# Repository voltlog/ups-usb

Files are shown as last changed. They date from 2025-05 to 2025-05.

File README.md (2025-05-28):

# ups-usb
This repo contains the isolated USB to serial board that I designed for a Serioux LD600LI UPS to get it to talk reliably with NUT.
Project was designed using Kicad V8.  For more information check out [Voltlog #503](https://youtu.be/ZeoCBQmW2Rw)
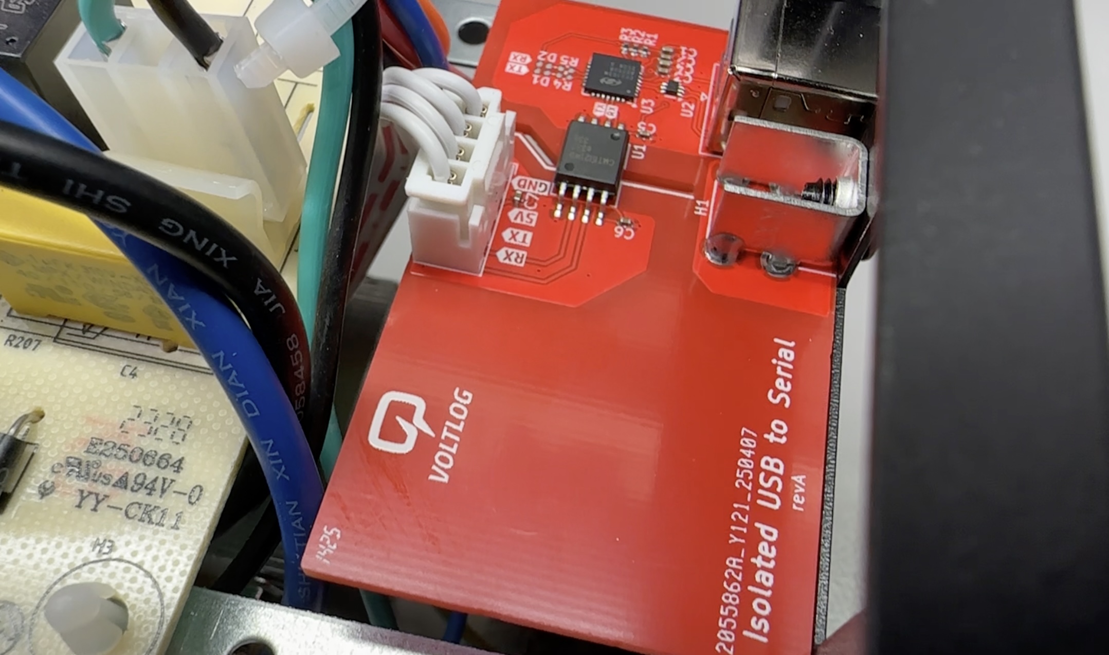
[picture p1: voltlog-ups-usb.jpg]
Image of the assembled PCB


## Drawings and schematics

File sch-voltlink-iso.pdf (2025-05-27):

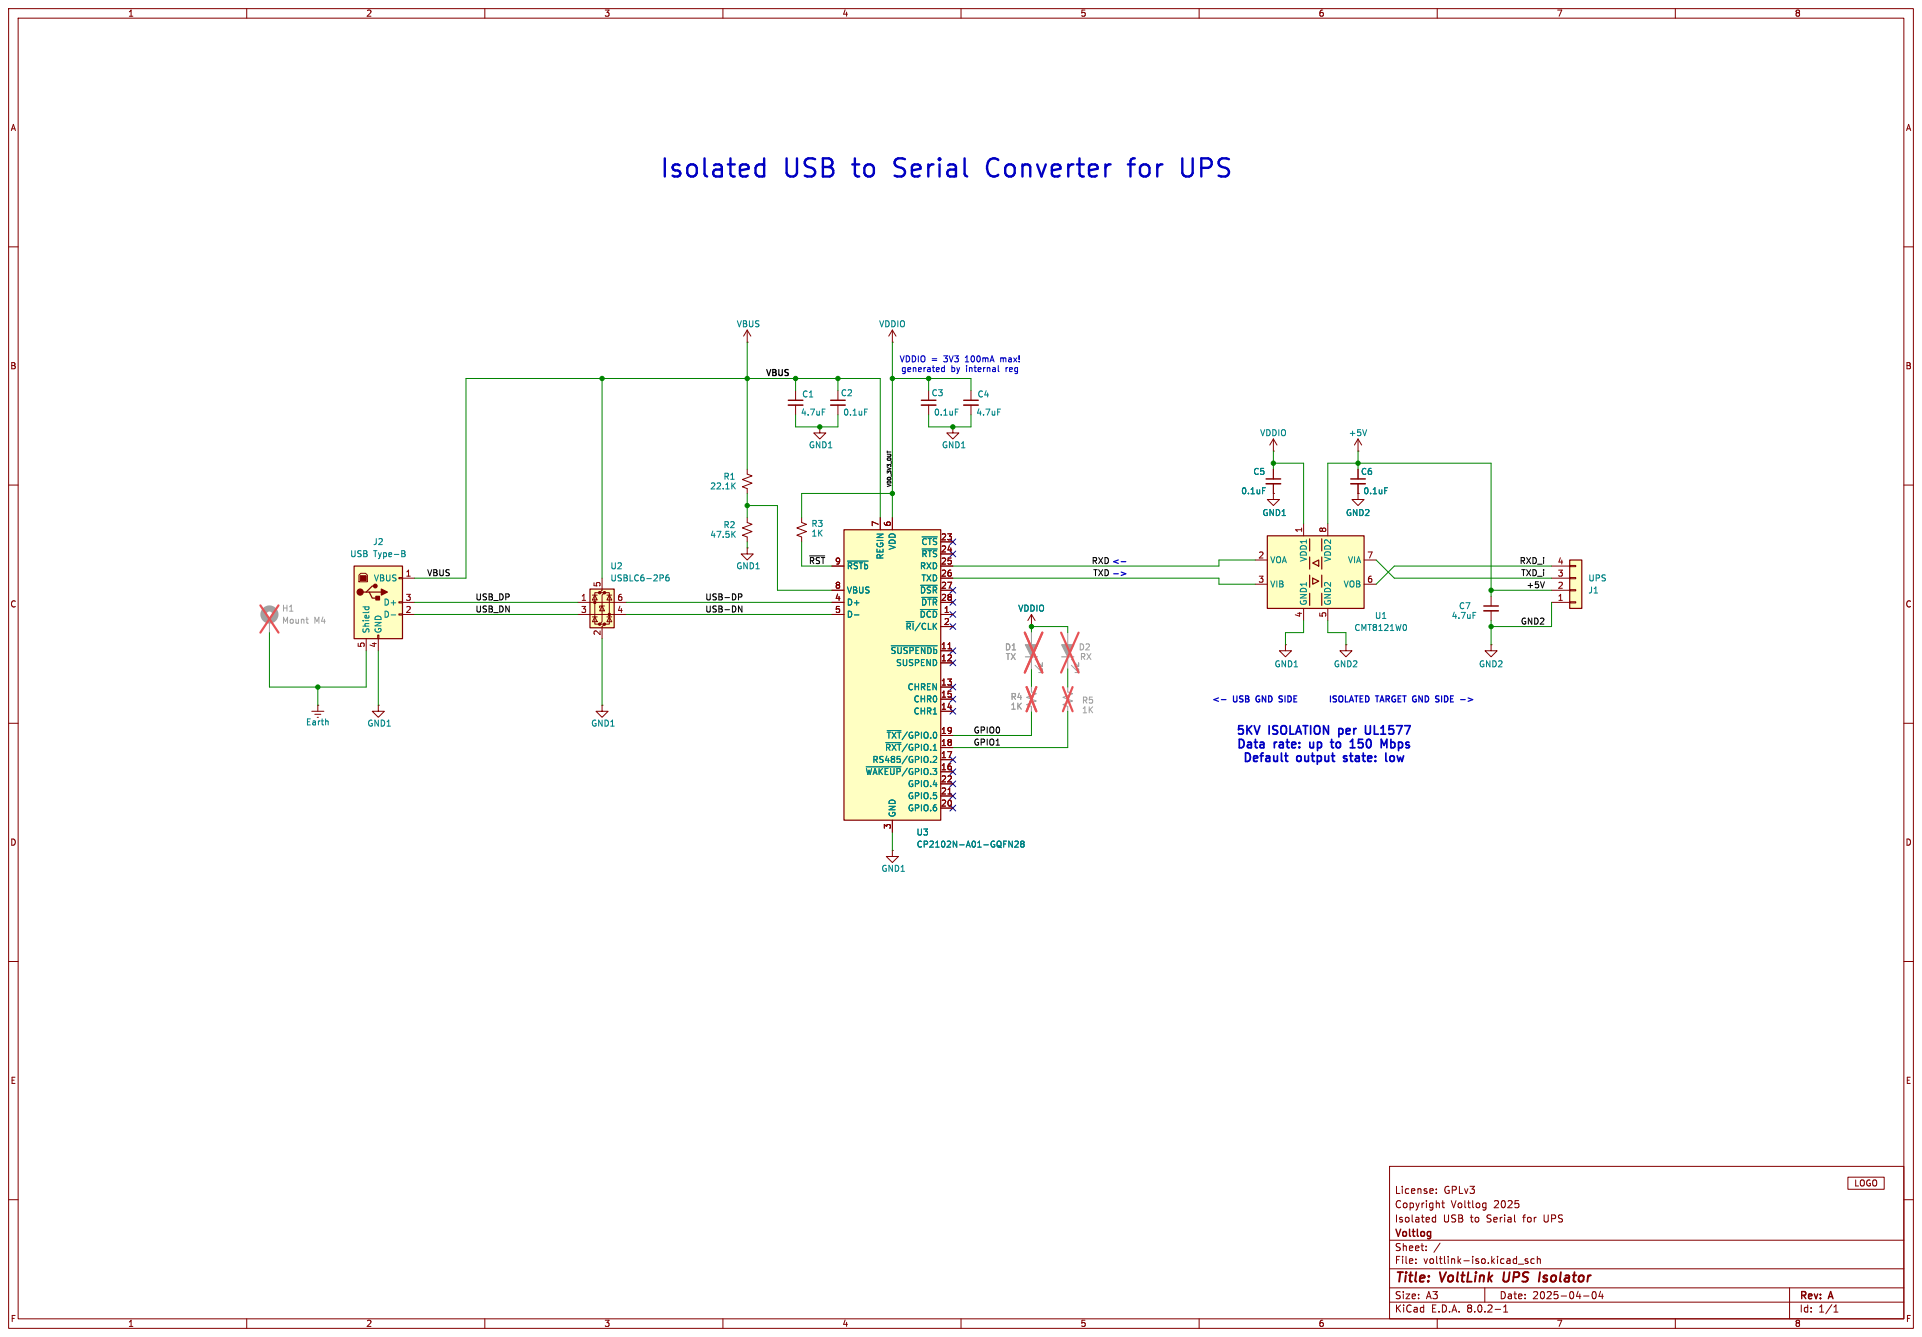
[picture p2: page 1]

<- Isolated USB to Serial Converter for UPS

ISOLATED TARGET GND SIDE -> VDDIO

Data rate: up to 150 Mbps
Default output state: low

Id: 1/1 Title: VoltLink UPS Isolator File: voltlink-iso.kicad_sch Sheet: / Voltlog

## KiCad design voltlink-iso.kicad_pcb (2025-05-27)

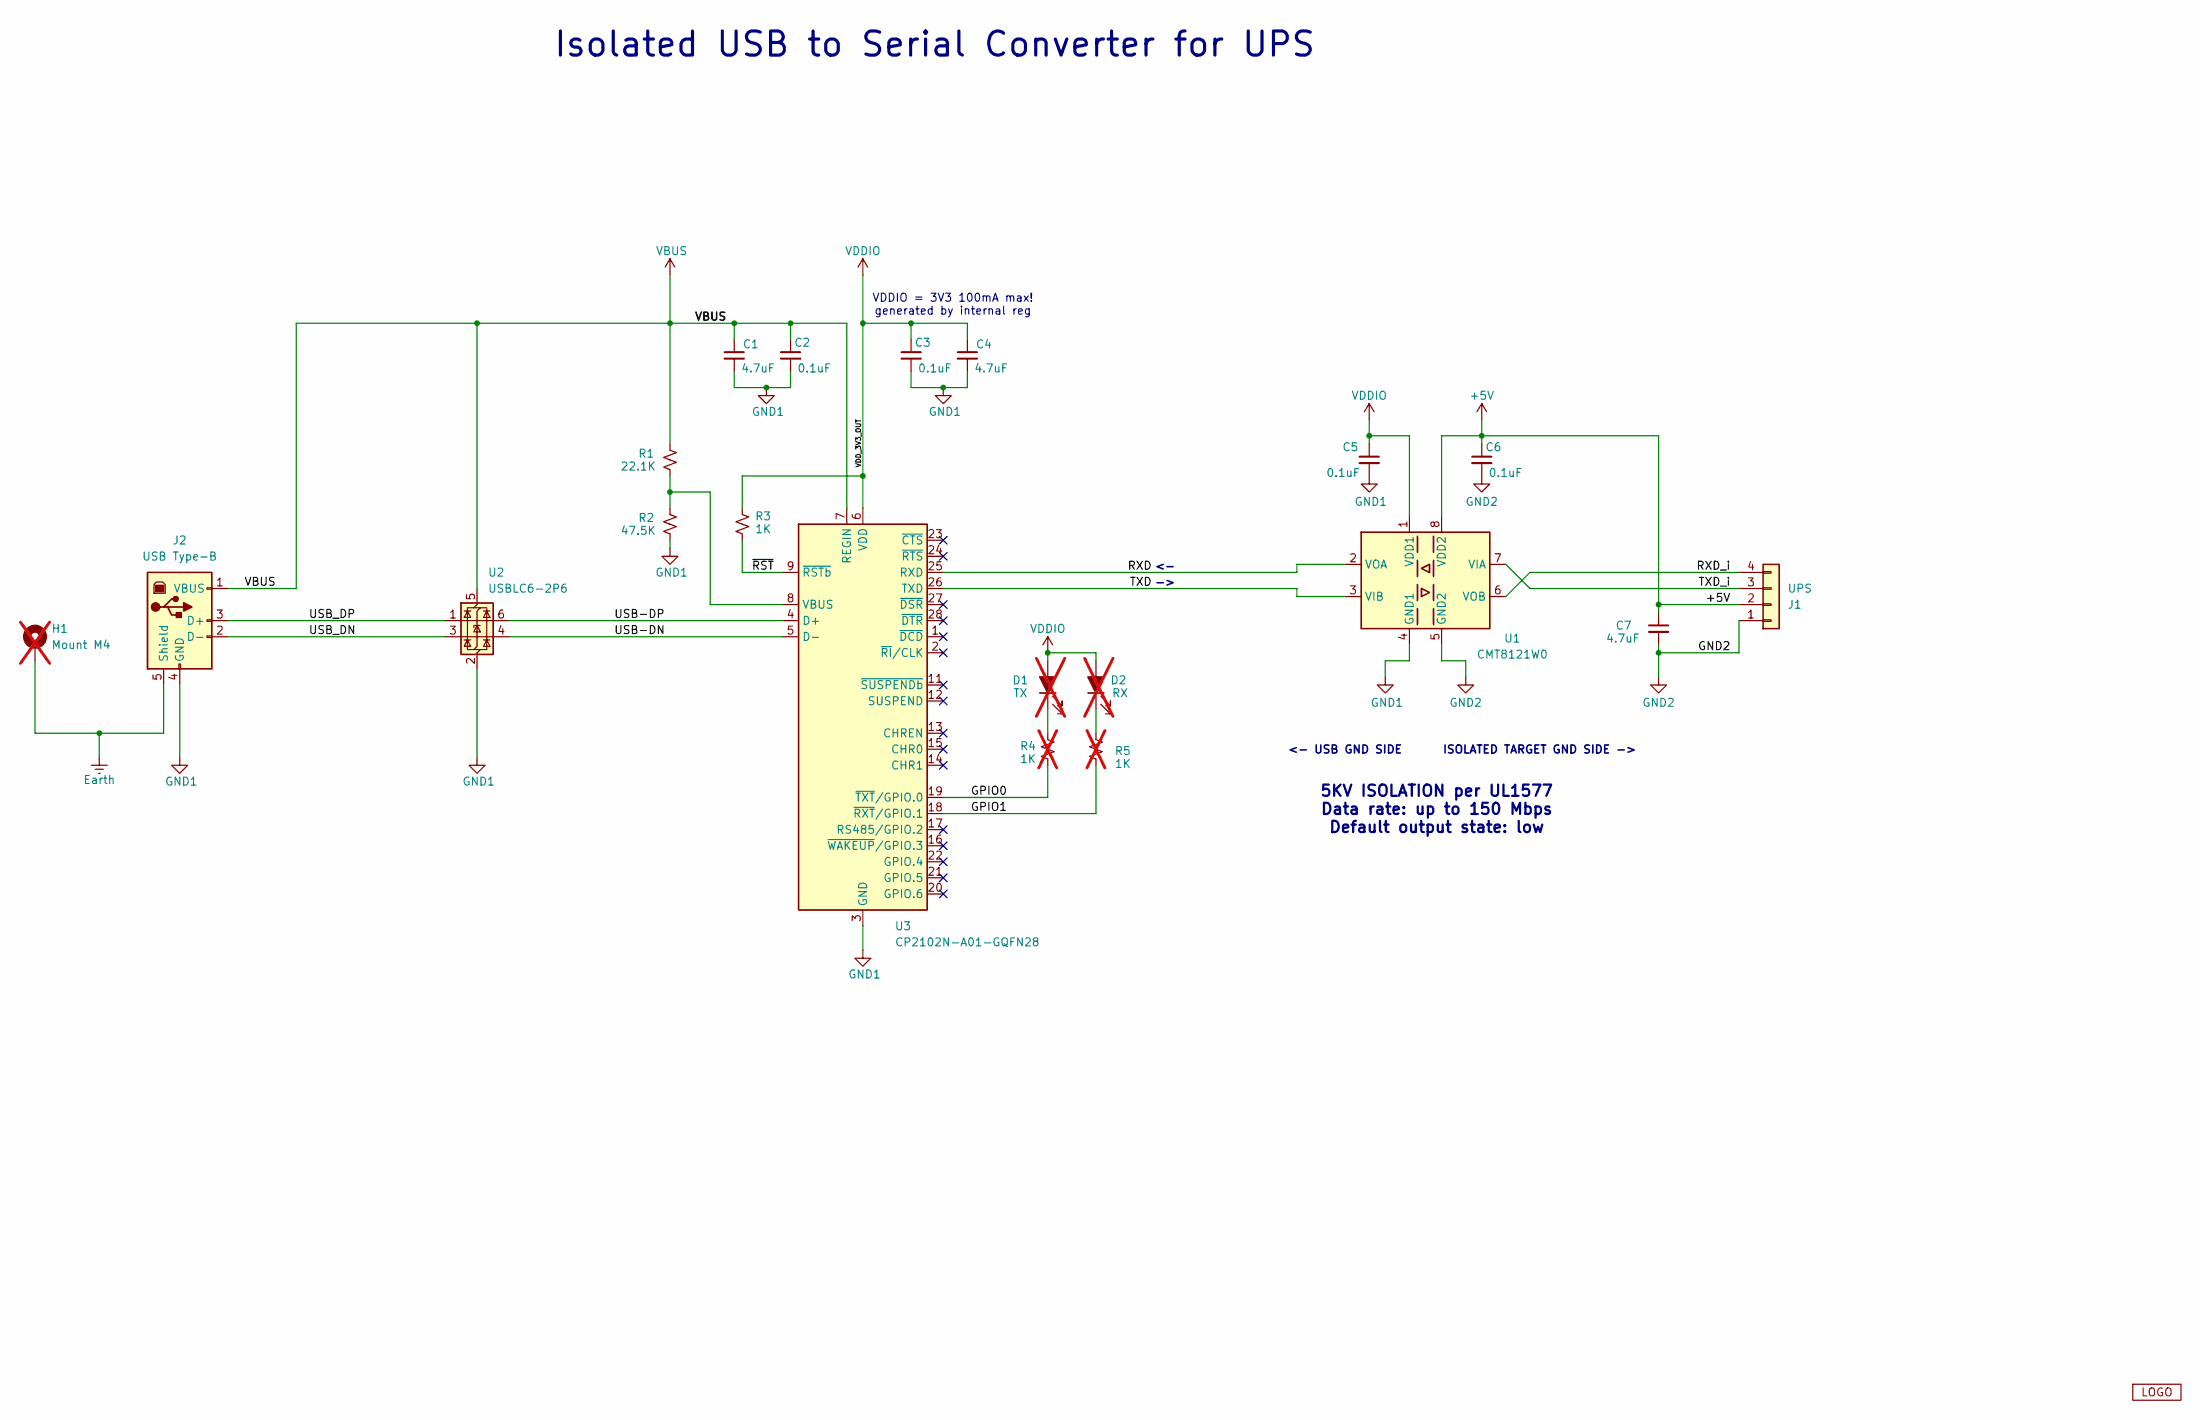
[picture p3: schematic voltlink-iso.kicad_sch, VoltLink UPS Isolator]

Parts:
C1, C4, C7: 4.7uF; C_0402_1005Metric; Voltage 10V; LCSC C23733
C2, C3, C5, C6: 0.1uF; C_0402_1005Metric; Voltage 50V; LCSC C307331
D1: TX; LED_0402_1005Metric; LCSC C130723; not fitted
D2: RX; LED_0402_1005Metric; LCSC C130719; not fitted
H1: Mount M4; M4_TH_terminal; not fitted
J1: UPS; JST_XH_B4B-XH-A_1x04_P2.50mm_Vertical; LCSC C19271370
J2: USB Type-B; USB_B_Lumberg_2411_02_Horizontal; LCSC C720549
R1: 22.1K; R_0402_1005Metric; LCSC C43473
R2: 47.5K; R_0402_1005Metric; LCSC C25896
R3: 1K; R_0402_1005Metric; LCSC C11702
R4, R5: 1K; R_0402_1005Metric; LCSC C11702; not fitted
U1: CMT8121W0; SOIC-8_7.5x5.85mm_P1.27mm; LCSC C32713182
U2: USBLC6-2P6; SOT-666; LCSC C2827693
U3: CP2102N-A01-GQFN28; QFN-28-1EP_5x5mm_P0.5mm_EP3.35x3.35mm; LCSC C1550553
V1: VOLTLOG_LOGO; voltlog_silk_5mm

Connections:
+5V: C6.1, C7.1, J1.2, U1.8 (VDD2)
/GPIO0: R4.1, U3.19 (~TXT/GPIO.0)
/GPIO1: R5.1, U3.18 (~RXT/GPIO.1)
/RXD: U1.2 (VOA), U3.25 (RXD)
/RXD_i: J1.4, U1.6 (VOB)
/TXD: U1.3 (VIB), U3.26 (TXD)
/TXD_i: J1.3, U1.7 (VIA)
/USB-DN: U2.4 (I/O2), U3.5 (D-)
/USB-DP: U2.6 (I/O1), U3.4 (D+)
/USB_DN: J2.2 (D-), U2.3 (I/O2)
/USB_DP: J2.3 (D+), U2.1 (I/O1)
/~RST: R3.1, U3.9 (~RSTb)
Earth: H1.1, J2.5 (Shield)
GND1: C1.2, C2.2, C3.2, C4.2, C5.2, J2.4 (GND), R2.2, U1.4 (GND1), U2.2 (GND), U3.3 (GND), U3.29 (GND)
GND2: C6.2, C7.2, J1.1, U1.5 (GND2)
unnamed: D1.1 (K), R4.2
unnamed: D2.1 (K), R5.2
unnamed: R1.2, R2.1, U3.8 (VBUS)
VBUS: C1.1, C2.1, J2.1 (VBUS), R1.1, U2.5 (VBUS), U3.7 (REGIN)
VDDIO: C3.1, C4.1, C5.1, D1.2 (A), D2.2 (A), R3.2, U1.1 (VDD1), U3.6 (VDD)

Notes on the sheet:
Isolated USB to Serial Converter for UPS
<- USB GND SIDE
5KV ISOLATION per UL1577 Data rate: up to 150 Mbps Default output state: low
ISOLATED TARGET GND SIDE ->
VDDIO = 3V3 100mA max! generated by internal reg

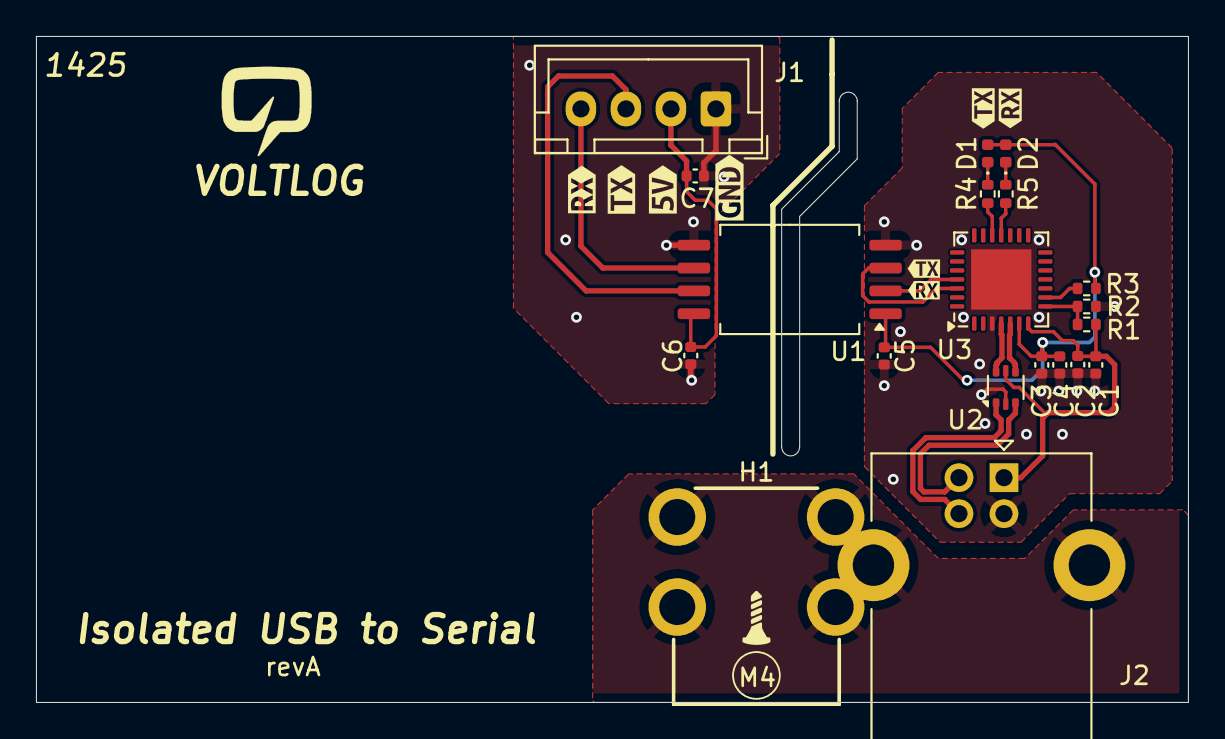
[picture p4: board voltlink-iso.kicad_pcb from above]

Board: 2 copper layers, 64.0 x 37.0 mm, 29 parts (0 on the bottom side), 20 nets.

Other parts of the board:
kibuzzard-67EF7DAE: G***; kibuzzard-67EF7DAE
kibuzzard-67EF7DB2: G***; kibuzzard-67EF7DB2
kibuzzard-67EF87AE: G***; kibuzzard-67EF87AE
kibuzzard-67EF88A2: G***; kibuzzard-67EF88A2
kibuzzard-67EF879C: G***; kibuzzard-67EF879C
kibuzzard-67EF8788: G***; kibuzzard-67EF8788
kibuzzard-67EF8792: G***; kibuzzard-67EF8792
kibuzzard-67EF8898: G***; kibuzzard-67EF8898

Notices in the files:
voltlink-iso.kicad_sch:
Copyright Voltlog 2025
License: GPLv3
